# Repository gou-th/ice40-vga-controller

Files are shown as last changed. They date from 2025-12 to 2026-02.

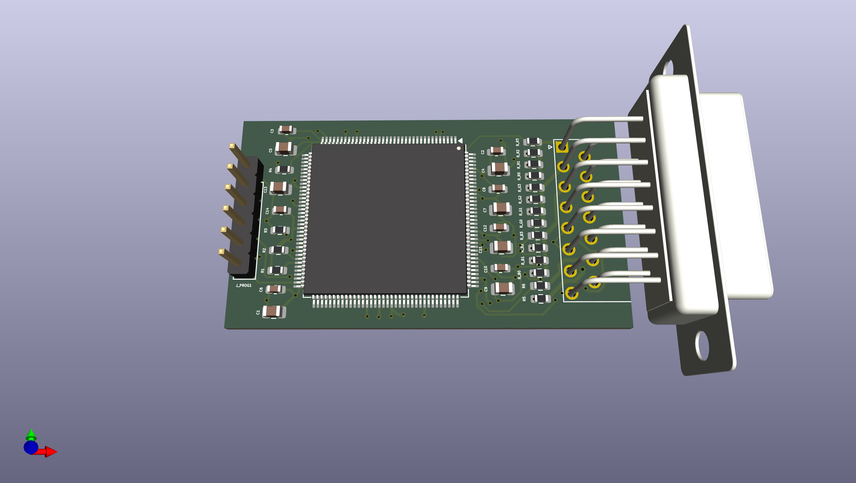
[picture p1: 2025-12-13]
kicad/model/vga_3d_1.png

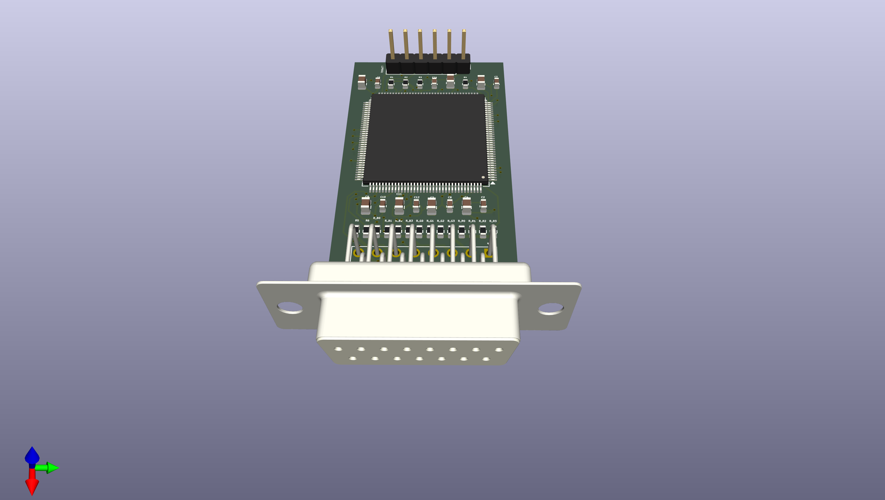
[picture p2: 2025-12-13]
kicad/model/vga_3d_2.png

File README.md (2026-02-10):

# ice40-vga-controller

A custom FPGA-based VGA controller designed for **640×480 @ 60 Hz**, implementing VGA timing generation, pixel logic and a **4-layer PCB** using the **Lattice iCE40HX1K** FPGA.

---

## Overview

This project implements a minimal yet fully functional VGA video controller without using vendor IP cores. The design follows a complete hardware development flow, starting from logic validation and RTL simulation to a manufacturable multilayer PCB.

The controller generates standard VGA sync signals and RGB video output compatible with conventional VGA displays.

---

## Architecture

The system is divided into three main functional blocks:

### VGA Timing Generation

* Horizontal and vertical pixel counters
* HSYNC and VSYNC pulse generation
* Active video region detection based on VGA timing parameters

### Pixel Generation

* RGB pixel values derived from current pixel coordinates
* Simple scrolling color-bar test pattern
* 4-bit color depth per RGB channel

### Hardware Output

* Digital RGB converted to analog VGA levels using a resistor ladder DAC
* Standard DE-15 VGA connector interface
* FPGA I/O powered at 3.3 V with proper decoupling

---

## Implementation Flow

### Logic Validation

Initial VGA timing was verified using Digital simulation software to confirm counter behavior, sync pulse timing and active display window alignment.

Reference: [`Digital`](./digital)

### RTL Design and Simulation

The design is implemented in SystemVerilog using a modular structure:

* [`vga_timing.sv`](./systemverilog/rtl/vga_timing.sv) – VGA timing and sync generation
* [`vga_pixel_gen.sv`](./systemverilog/rtl/vga_pixel_gen.sv) – RGB pixel generation
* [`vga_timing_tb.sv`](./systemverilog/sim/vga_timing_tb.sv) – Testbench for waveform-level verification

References:

* RTL: [`RTL`](./systemverilog/rtl)
* Simulation: [`Simulation & Waveform`](./systemverilog/sim)

### PCB Design

A complete 4-layer PCB was designed in KiCad to host the VGA controller.

Layer stackup:

* Top: Signal routing
* Inner 1: Ground plane
* Inner 2: Power planes
* Bottom: Signal routing

Key hardware features:

* Lattice iCE40HX1K FPGA
* Dedicated core and I/O power planes
* Local decoupling on all power pins
* VGA DAC placed close to FPGA outputs

References:

* Schematic:  [`Schematic`](./kicad/schematic)
* PCB: [`PCB`](./kicad/pcb)
* Gerbers: [`Gerber`](./kicad/gerber)

---

## 3D PCB View

<p align="center">
  
</p>

---

### Folder Structure

<pre>
ice40-vga-controller/
├── digital/                # VGA timing validation using Digital simulation tool
├── systemverilog/
│   ├── rtl/                # SystemVerilog RTL source files
│   └── sim/                # Testbench and simulation files
├── kicad/
│   ├── schematic/          # Circuit schematics
│   ├── pcb/                # PCB layout files
│   └── gerber/             # Manufacturing Gerber files
└── README.md
</pre>

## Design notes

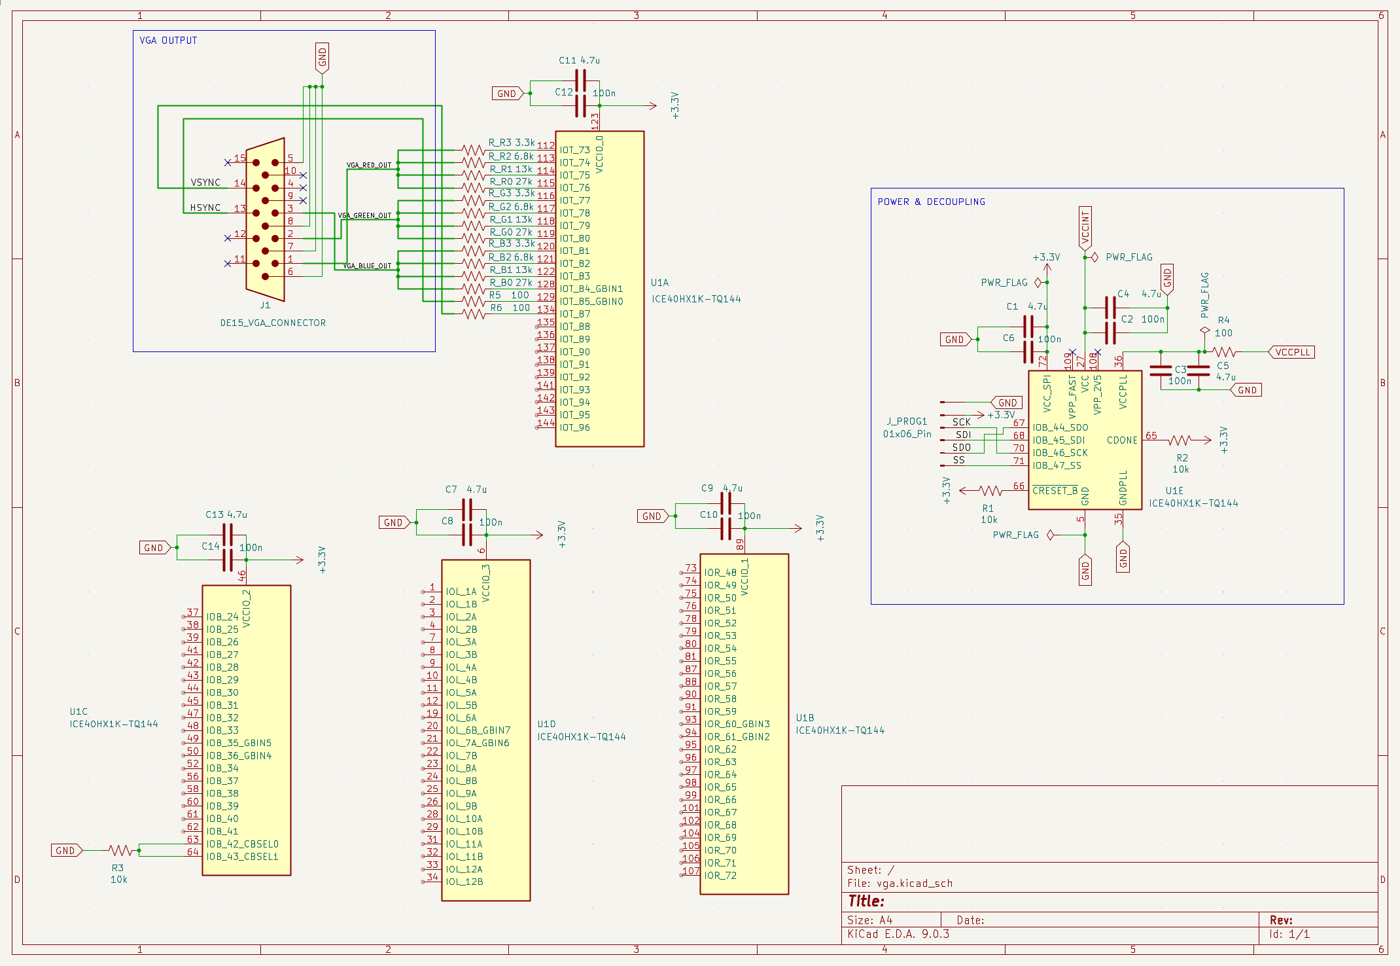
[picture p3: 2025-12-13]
kicad/schematic/schematic.png

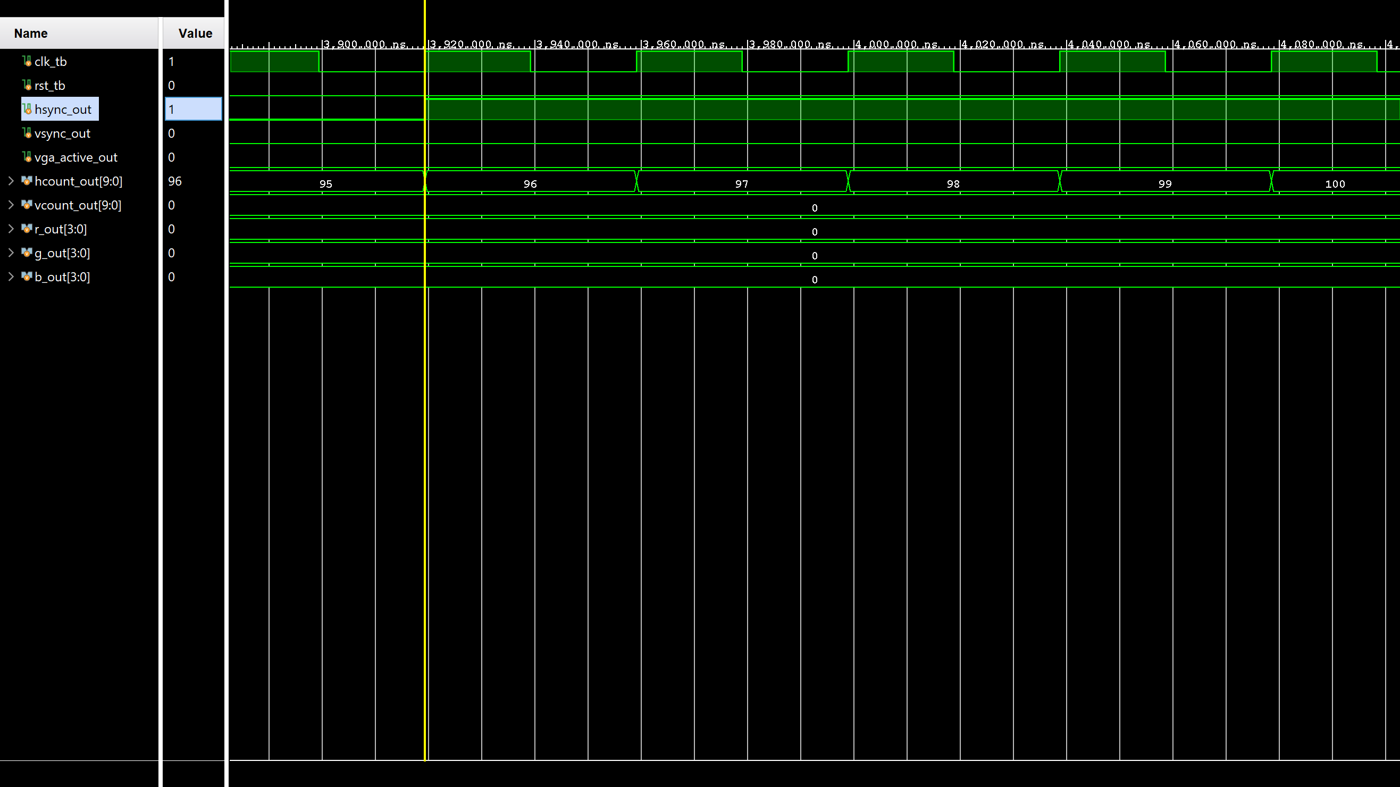
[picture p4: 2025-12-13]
systemverilog/sim/waveform/h_sync_start.png

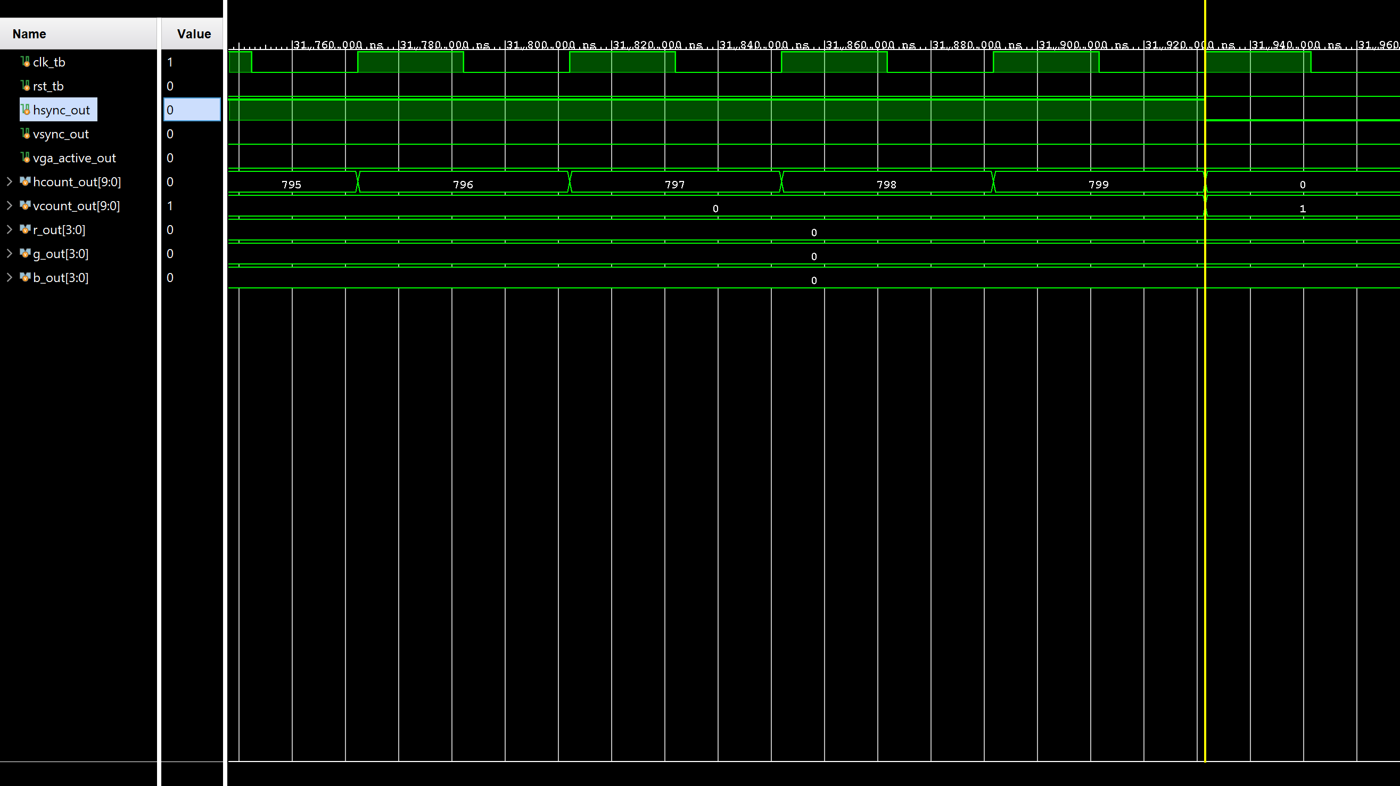
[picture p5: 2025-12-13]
systemverilog/sim/waveform/h_sync_end.png

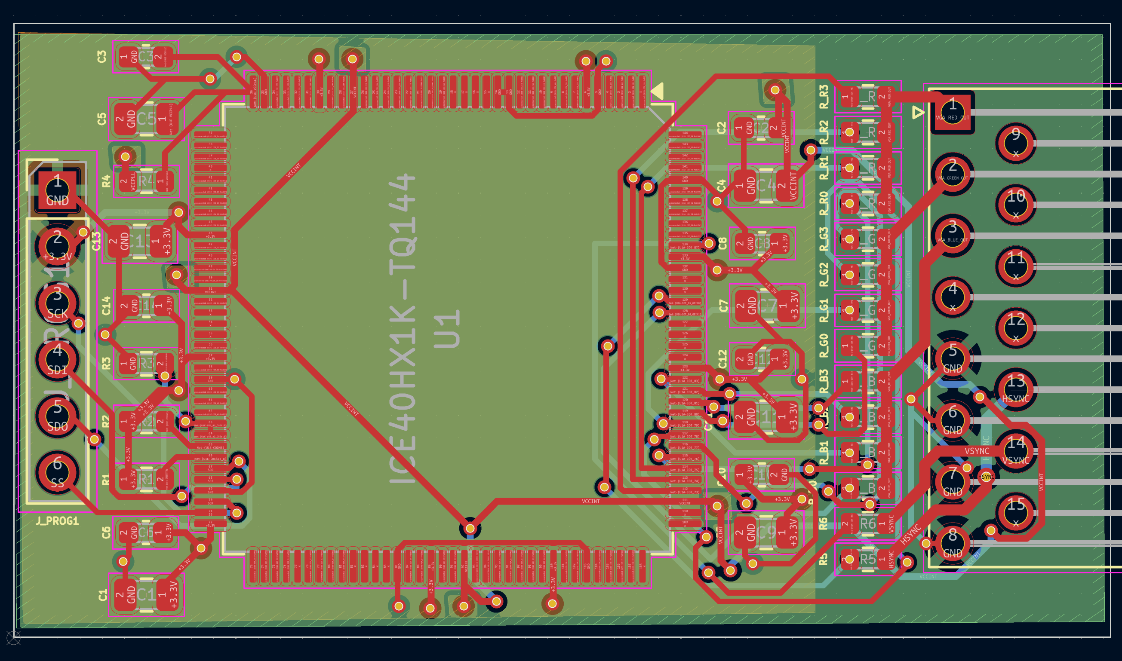
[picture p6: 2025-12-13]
kicad/pcb/pcb_top_layer.png

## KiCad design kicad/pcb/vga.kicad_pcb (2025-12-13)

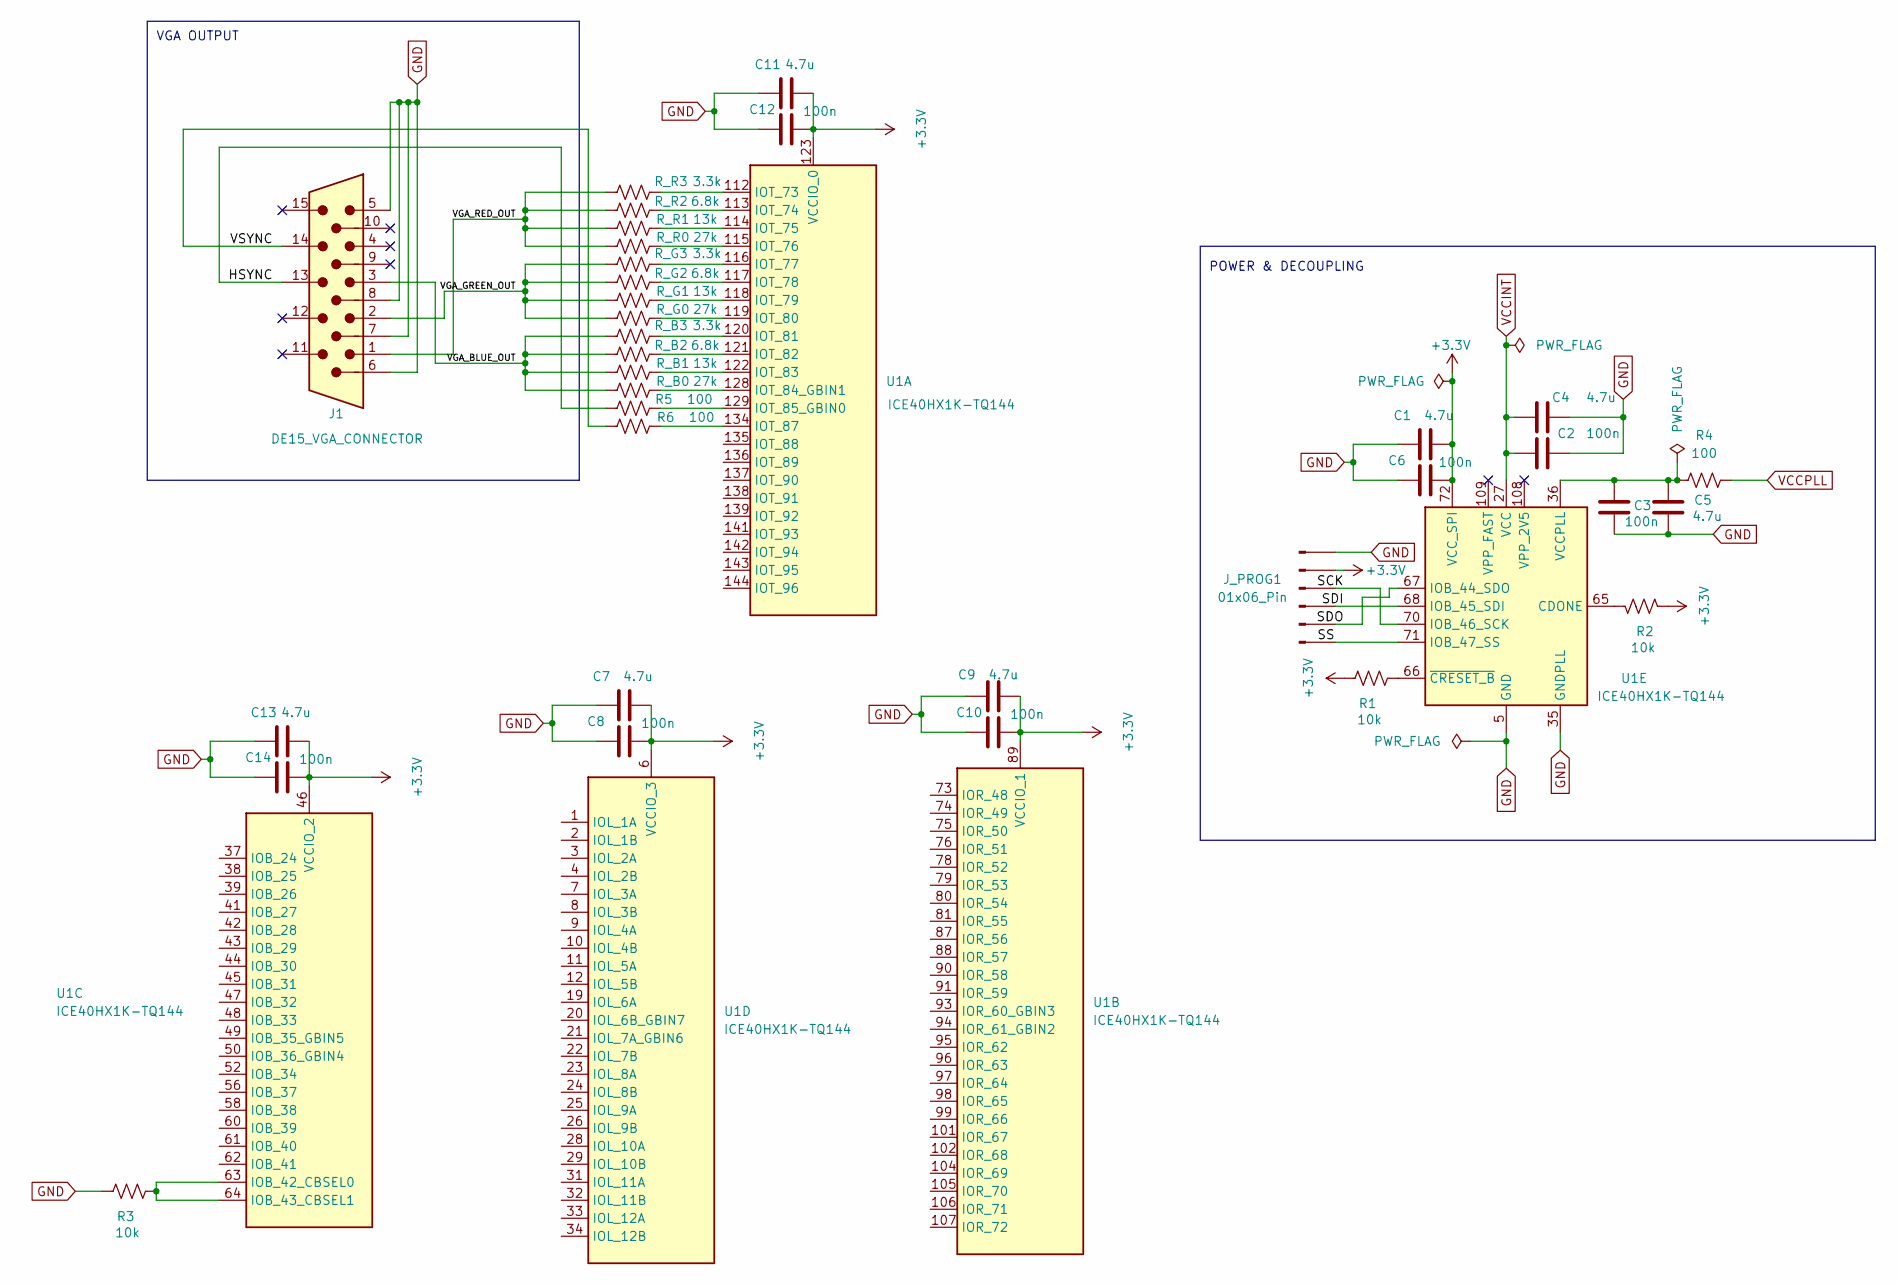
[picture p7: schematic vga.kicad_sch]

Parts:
C1, C4, C5, C7, C9, C11, C13: 4.7u; C_0805_2012Metric
C2, C3, C6, C8, C10, C12, C14: 100n; C_0603_1608Metric
J1: DE15_VGA_CONNECTOR; DSUB-15_Socket_Horizontal_P2.77x2.84mm_EdgePinOffset9.40mm
J_PROG1: 01x06_Pin; PinHeader_1x06_P2.54mm_Vertical
R1, R2, R3: 10k; R_0603_1608Metric
R4, R5, R6: 100; R_0603_1608Metric
R_B0: 27k; R_0603_1608Metric
R_B1: 13k; R_0603_1608Metric
R_B2: 6.8k; R_0603_1608Metric
R_B3: 3.3k; R_0603_1608Metric
R_G0: 27k; R_0603_1608Metric
R_G1: 13k; R_0603_1608Metric
R_G2: 6.8k; R_0603_1608Metric
R_G3: 3.3k; R_0603_1608Metric
R_R0: 27k; R_0603_1608Metric
R_R1: 13k; R_0603_1608Metric
R_R2: 6.8k; R_0603_1608Metric
R_R3: 3.3k; R_0603_1608Metric
U1: ICE40HX1K-TQ144; TQFP-144_20x20mm_P0.5mm

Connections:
+3.3V: C1.1, C6.1, C7.1, C8.1, C9.1, C10.1, C11.1, C12.1, C13.1, C14.1, J_PROG1.2, R1.1, R2.1, U1.6 (VCCIO_3), U1.30 (VCCIO_3), U1.46 (VCCIO_2), U1.57 (VCCIO_2), U1.72 (VCC_SPI), U1.89 (VCCIO_1), U1.100 (VCCIO_1), U1.123 (VCCIO_0), U1.133 (VCCIO_0)
/HSYNC: J1.13, R5.1
/SCK: J_PROG1.3, U1.70 (IOB_46_SCK)
/SDI: J_PROG1.4, U1.68 (IOB_45_SDI)
/SDO: J_PROG1.5, U1.67 (IOB_44_SDO)
/SS: J_PROG1.6, U1.71 (IOB_47_SS)
/VGA_BLUE_OUT: J1.3, R_B0.2, R_B1.2, R_B2.2, R_B3.2
/VGA_GREEN_OUT: J1.2, R_G0.2, R_G1.2, R_G2.2, R_G3.2
/VGA_RED_OUT: J1.1, R_R0.2, R_R1.2, R_R2.2, R_R3.2
/VSYNC: J1.14, R6.1
GND: C1.2, C2.1, C3.1, C4.1, C5.2, C6.2, C7.2, C8.2, C9.2, C10.2, C11.2, C12.2, C13.2, C14.2, J1.5, J1.6, J1.7, J1.8, J_PROG1.1, R3.1, U1.5 (GND), U1.13 (GND), U1.14 (GND), U1.35 (GNDPLL), U1.59 (GND), U1.69 (GND), U1.86 (GND), U1.103 (GND), U1.132 (GND), U1.140 (GND)
unnamed: R_R3.1, U1.112 (IOT_73)
unnamed: R_R2.1, U1.113 (IOT_74)
unnamed: R_R1.1, U1.114 (IOT_75)
unnamed: R_R0.1, U1.115 (IOT_76)
unnamed: R_G3.1, U1.116 (IOT_77)
unnamed: R_G2.1, U1.117 (IOT_78)
unnamed: R_G1.1, U1.118 (IOT_79)
unnamed: R_G0.1, U1.119 (IOT_80)
unnamed: R_B3.1, U1.120 (IOT_81)
unnamed: R_B2.1, U1.121 (IOT_82)
unnamed: R_B1.1, U1.122 (IOT_83)
unnamed: R_B0.1, U1.128 (IOT_84_GBIN1)
unnamed: R5.2, U1.129 (IOT_85_GBIN0)
unnamed: R6.2, U1.134 (IOT_87)
unnamed: R3.2, U1.63 (IOB_42_CBSEL0), U1.64 (IOB_43_CBSEL1)
unnamed: R2.2, U1.65 (CDONE)
unnamed: C3.2, C5.1, R4.1, U1.36 (VCCPLL)
unnamed: R1.2, U1.66 (~CRESET_B)
VCCINT: C2.2, C4.2, U1.27 (VCC), U1.51 (VCC), U1.92 (VCC), U1.111 (VCC)
VCCPLL: R4.2

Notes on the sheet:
VGA OUTPUT
POWER & DECOUPLING

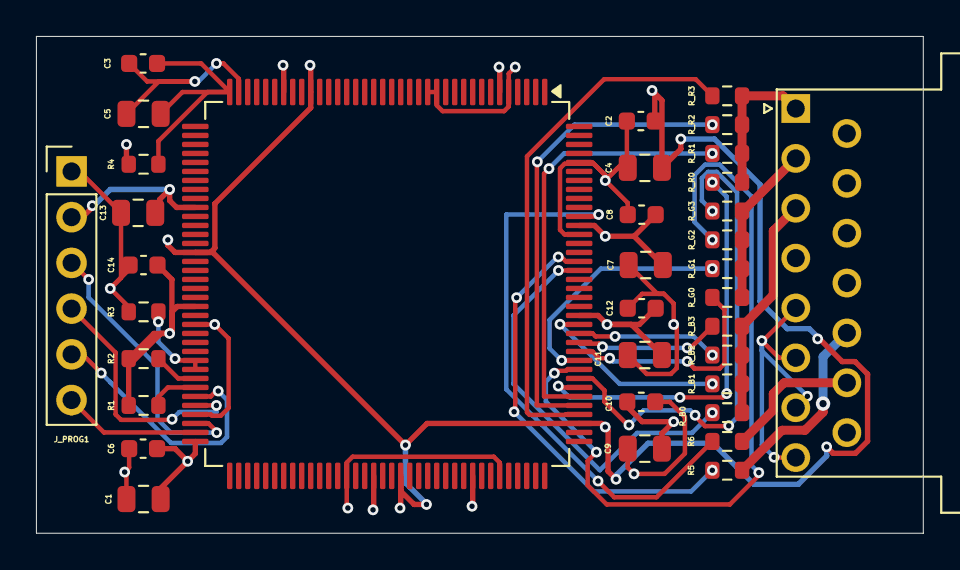
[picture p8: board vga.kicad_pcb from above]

Board: 4 copper layers, 49.3 x 27.6 mm, 35 parts (0 on the bottom side), 30 nets.
